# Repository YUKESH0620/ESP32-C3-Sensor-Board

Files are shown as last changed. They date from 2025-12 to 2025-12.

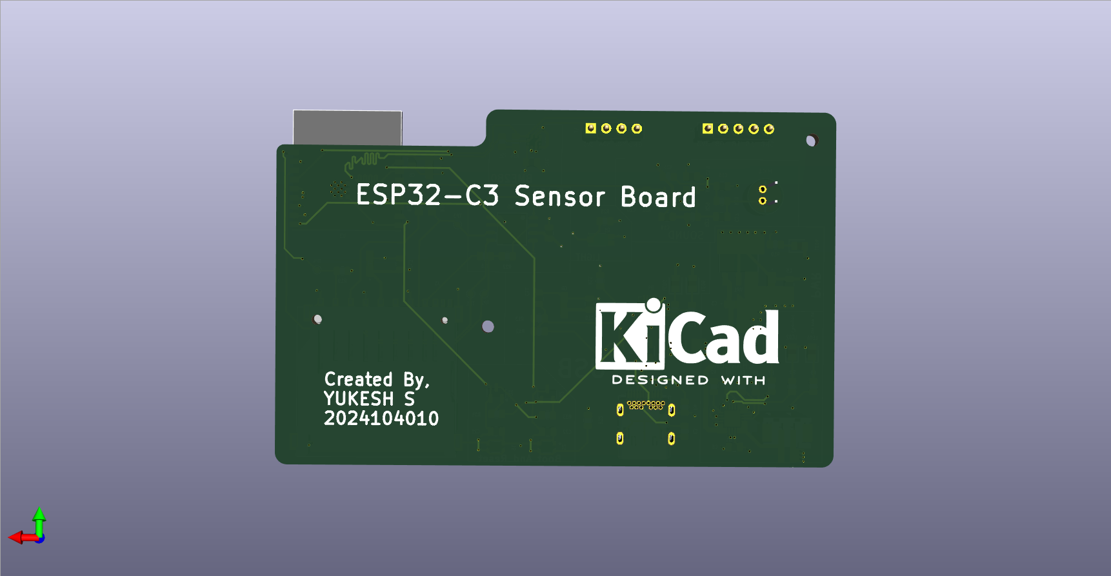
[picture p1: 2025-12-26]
images/3D_Renders/Screenshot 2025-12-26 091325.png

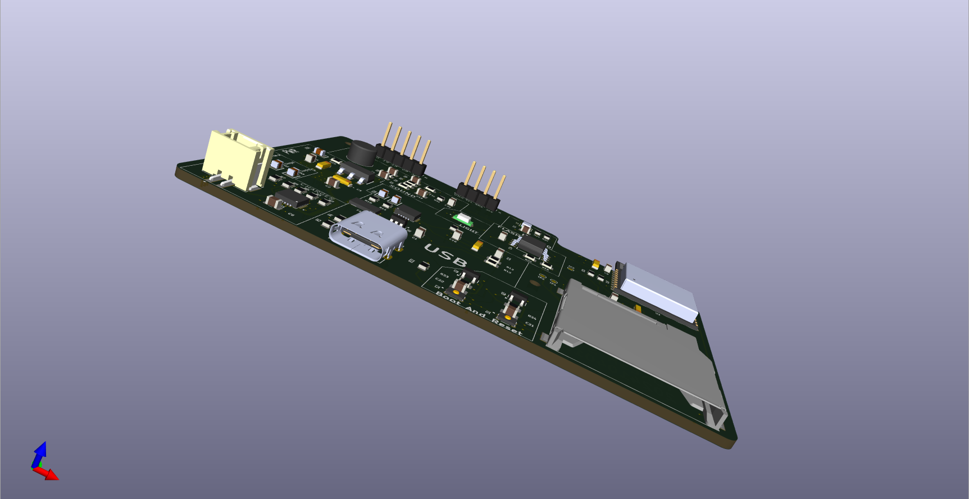
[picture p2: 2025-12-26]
images/3D_Renders/Screenshot 2025-12-26 091427.png

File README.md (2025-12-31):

# ESP32-C3 Smart Sensor Board

This repository contains the complete **hardware design** of a custom **ESP32-C3 based Smart Sensor Board**, including schematics, PCB layout, and documentation.

The design integrates **robust power management, multiple sensors, data storage, USB connectivity, and auto-programming**, making it suitable for **IoT, data logging, and embedded systems development**.

---

##  Board Images

###  Complete Schematic








###  PCB Layout


###  3D Views






---

##  System Architecture

### Functional Block Diagram
```text
USB-C / Li-Po Battery
│
MCP73831 Charger
│
+5V Rail
│
LM1117-3.3 LDO
│
+3.3V Rail
│
ESP32-C3 MCU
│ │ │ │
│ │ │ Microphone + MAX4466
│ │ BME280 (I2C)
│ LDR (ADC)
SD Card (SPI)
|
SPI Flash
```
---

##  Key Features

###  Power & Charging
- USB Type-C connector
- Li-Po charging using **MCP73831**
- JST battery connector
- LM1117-3.3 LDO regulator
- Power status LED

###  Microcontroller
- **ESP32-C3-WROOM-02**
- RISC-V core
- Wi-Fi + BLE
- USB-UART programmable

###  Sensors
- **BME280** – Temperature, humidity, pressure
- **Electret microphone + MAX4466 amplifier**
- **LDR photo sensor**

###  Storage
- SPI Flash memory (W25Q32)
- Micro SD card module (SPI)

###  Programming & Debug
- CP2102N USB-to-UART
- Auto-programming (DTR/RTS → EN/BOOT)
- Boot & Reset buttons
- Test points

---

##  Working Principle

### Power Section
- USB-C provides 5V
- MCP73831 safely charges Li-Po battery
- LM1117 converts 5V to regulated 3.3V
- Decoupling capacitors ensure stable rails

### MCU & Sensors
- ESP32-C3 communicates with:
  - BME280 via I²C
  - SD card & Flash via SPI
  - Microphone and LDR via ADC
- Data can be logged or transmitted wirelessly

### Programming
- USB-C → CP2102N
- DTR/RTS control BOOT & EN automatically
- Compatible with ESP-IDF and Arduino

---

## 🧾 Bill of Materials

###  Active Components

| Ref | Component | Value / Part |
|----|---|---|
| U1 | ESP32 MCU | ESP32-C3-WROOM-02 |
| U2 | Env Sensor | BME280 |
| U3 | USB-UART | CP2102N |
| U4 | Charger IC | MCP73831 |
| U5 | LDO Regulator | LM1117-3.3 |
| U6 | SPI Flash | W25Q32 |
| U7 | Mic Amplifier | MAX4466 |
| J1 | USB Connector | USB Type-C |
| J2 | Battery Connector | JST-PH-2 |
| J3 | SD Card Socket | SPI SD |

---

###  Resistors (From Schematic)

| Ref | Value | Purpose |
|----|---|---|
| R1 | 10kΩ | MCP73831 PROG |
| R2 | 10kΩ | MCP73831 PROG |
| R3 | 5.1kΩ | USB-C CC pull-down |
| R4 | 5.1kΩ | USB-C CC pull-down |
| R5 | 2kΩ | MCP73831 status |
| R6 | 20kΩ | MCP73831 status |
| R7 | 470Ω | Charging LED |
| R8 | 470Ω | Charged LED |
| R9 | 470Ω | Fault LED |
| R10 | 470Ω | Power LED |
| R11 | 1kΩ | USB VBUS link |
| R12 | 22.1kΩ | USB detection |
| R13 | 47.5kΩ | USB detection |
| R15 | 47k | Biasing resistor |
| R23 | 10kΩ | LDR voltage divider |
| R24 | 4.7kΩ | I²C pull-up |
| R25 | 4.7kΩ | I²C pull-up |
| R26 | 2kΩ | Mic bias |
| R27 | 1MΩ | Mic amp gain |
| R28 | 2kΩ | Mic bias |
| R29 | 1MΩ | Mic amp gain |
| R30 | 10kΩ | Mic amp |
| R31 | 2.2kΩ | Mic feedback |
| R32 | 10kΩ | Reset pull-up |
| R33 | 10kΩ | DTR control |
| R34 | 10kΩ | RTS control |

---

###  Capacitors (From Schematic)

| Ref | Value | Purpose |
|----|---|---|
| C1 | 0.1µF | USB decoupling |
| C2 | 0.1µF | LDO input |
| C3 | 10µF | LDO bulk |
| C4 | 10µF | LDO output |
| C5 | 0.1µF | LDO output |
| C6 | 1µF | MCP73831 |
| C7 | 10µF | ESP32 supply |
| C8 | 0.1µF | ESP32 decoupling |
| C10 | 0.1µF | Sensor decoupling |
| C14 | 0.1µF | Flash decoupling |
| C15 | 0.1µF | BME280 |
| C17 | 10nF | Mic coupling |
| C18 | 0.1µF | Mic supply |
| C19 | 1µF | Mic amp |
| C20 | 0.1µF | Mic feedback |
| C21 | 0.1µF | BOOT debounce |
| C22 | 1µF | RESET debounce |

---

##  Design Considerations

- Ground plane for EMI reduction
- ESP32 antenna keep-out respected
- Separate analog routing for microphone
- Decoupling capacitors close to ICs
- USB-C CC resistors correctly implemented
- Battery charging current set safely

---

##  Testing Strategy

- Power rail validation
- USB enumeration
- Battery charge & termination test
- Sensor I²C/SPI verification
- SD card read/write
- ADC noise testing (mic & LDR)

---
##  Revision History

### Rev-A (Initial Prototype)
- ESP32-C3 based sensor board
- Microphone connected to GPIO5 (ADC conflict with Wi-Fi)
- Fixed-gain microphone amplifier
- Photosensor output taken from incorrect pin
- No additional EMI filtering on power path

### Rev-B (Improved Design – Current)
- Resolved ADC conflict between Wi-Fi and microphone
- Improved analog signal quality
- Added EMI noise suppression
- Improved user interface and usability
---

##  Key Engineering Fixes & Improvements

ESP32 PCB prototype 2 improvements and fixes

### 1. ADC Conflict Resolution (Wi-Fi vs Microphone)
- Issue identified during testing: GPIO5 ADC unavailable when Wi-Fi is active
- Root cause: ADC resource conflict on ESP32-C3
- Solution:
  - Microphone OUT moved from GPIO5 → GPIO0 (ADC1)
  - CS_SD reassigned to GPIO5 as digital output
- Result: Microphone and Wi-Fi now operate simultaneously without conflict

### 2. Variable Gain Microphone Amplifier
- Replaced fixed gain network with trimmer potentiometer
- Gain range adjustable from **25× to 125×**
- Improves adaptability for different acoustic environments

### 3. Photosensor Signal Correction
- Output pin corrected from pin 3 → pin 1 as per datasheet
- Added RC filtering capacitors for noise reduction
- Result: Stable and accurate ADC readings

### 4. Analog Noise Reduction
- Added local decoupling capacitor near GPIO0 (MIC_OUT)
- Reduced high-frequency noise on ADC line

### 5. Improved User Interface
- Replaced small tact switches with larger buttons
- Better usability and reliability

### 6. Power Integrity Enhancement
- Added ferrite bead on charger output
- Purpose:
  - Suppress high-frequency switching noise from MCP73871
  - Reduce EMI affecting analog and RF sections

---
##  Design Status

- Rev-A: Initial schematic completed and reviewed
- Design improvements identified during schematic review
- Rev-B incorporates recommended fixes and optimizations
- Hardware fabrication and testing are pending

Note: Functional validation will be performed after PCB fabrication.

---
##  Validation Plan (Post-Fabrication)

- Verify Wi-Fi and microphone operation simultaneously
- Validate ADC stability for photosensor input
- Measure microphone gain range
- Check power rail noise and EMI behavior
- Confirm battery charging and boost operation

---

##  Applications

- Environmental monitoring
- IoT data logger
- Smart sensor node
- Academic & portfolio project
- Embedded systems experimentation

---

##  Future Enhancements

- Fuel gauge IC
- Enclosure design
- OTA firmware support
- EMI compliance testing
- Low-power optimization

---

## 👤 Author

**Yukesh S**  
Embedded Systems Enthusiast  

---

## 📜 License

This project is licensed under the MIT License.

You are free to use, modify, distribute, and commercialize this design,
provided that the original copyright notice and license text are included.

See the [LICENSE](LICENSE) file for full details.

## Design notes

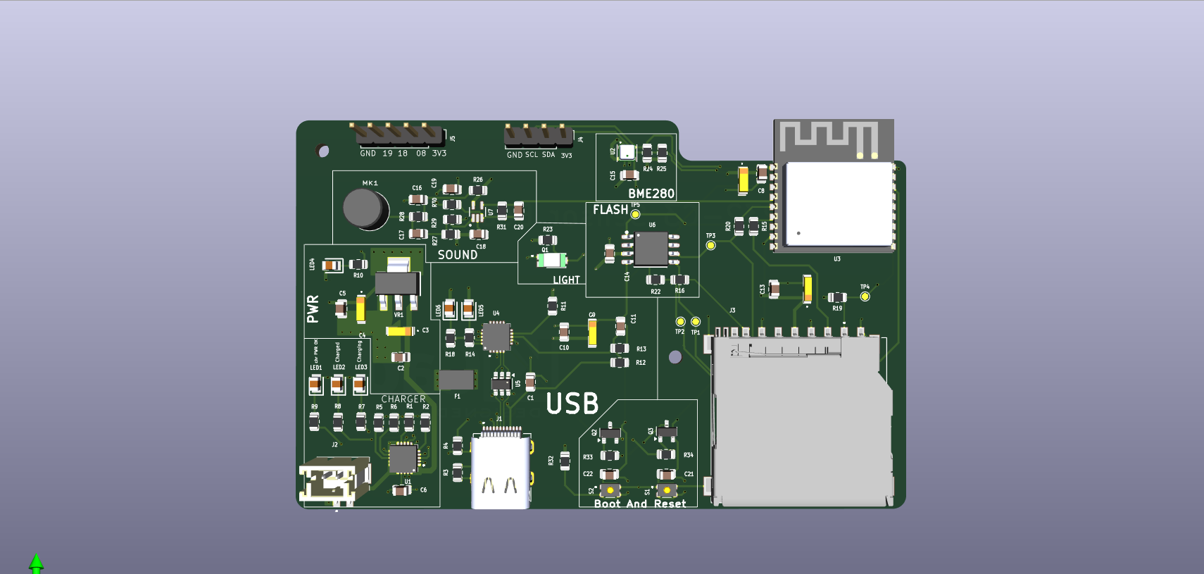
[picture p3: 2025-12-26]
images/3D_Renders/Screenshot 2025-12-26 091250.png

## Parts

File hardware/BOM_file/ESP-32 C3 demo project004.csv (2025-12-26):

ID | Designator | FootprintQuantity | Quantity | Designation | Supplier and ref
1 | C1 | C_0805_2012Metric | 1 | 0.1u
2 | C2 | C_0805_2012Metric | 1 | 0.1u
3 | C3 | C_0805_2012Metric | 1 | 10u
4 | C4 | C_0805_2012Metric | 1 | 10u
5 | C5 | C_0805_2012Metric | 1 | 0.1u
6 | C6 | C_0805_2012Metric | 1 | 1u
7 | C7 | C_0805_2012Metric | 1 | 10u
8 | C8 | C_0805_2012Metric | 1 | 0.1u
9 | C9 | C_0805_2012Metric | 1 | 4.7u
10 | C10 | C_0805_2012Metric | 1 | 0.1u
11 | C11 | C_0805_2012Metric | 1 | 1u
12 | C12 | C_0805_2012Metric | 1 | 10u
13 | C13 | C_0805_2012Metric | 1 | 0.1u
14 | C14 | C_0805_2012Metric | 1 | 0.1u
15 | C15 | C_0805_2012Metric | 1 | 0.1u
16 | C16 | C_0805_2012Metric | 1 | 0.1u
17 | C17 | C_0805_2012Metric | 1 | 10n
18 | C18 | C_0805_2012Metric | 1 | 0.1u
19 | C19 | C_0805_2012Metric | 1 | 1u
20 | C20 | C_0805_2012Metric | 1 | 0.1u
21 | C21 | C_0805_2012Metric | 1 | 0.1u
22 | C22 | C_0805_2012Metric | 1 | 1u
23 | F1 | FUSC3226X100N | 1 | 0ZCH0110AF2E
24 | J1 | BELFUSE_SS-52400-002 | 1 | SS-52400-002
25 | J2 | JST_B2B-PH-SM4-TB | 1 | B2B-PH-SM4-TB
26 | J3 | AMPHENOL_GSD090012SEU | 1 | B2B-PH-SM4-TB
27 | J4 | PinHeader_1x04_P2.54mm_Vertical | 1 | Conn_01x04_Pin
28 | J5 | PinHeader_1x05_P2.54mm_Vertical | 1 | Conn_01x05_Pin
29 | LED1 | LEDC2012X120N | 1 | LTST-C170TBKT
30 | LED2 | LEDC2012X120N | 1 | LTST-C170TBKT
31 | LED3 | LEDC2012X120N | 1 | LTST-C170TBKT
32 | LED4 | LEDC2012X120N | 1 | LTST-C170TBKT
33 | LED5 | LEDC2012X120N | 1 | LTST-C170TBKT
34 | LED6 | LEDC2012X120N | 1 | LTST-C170TBKT
35 | MK1 | CUI_CMC-5042PF-AC | 1 | CMC-5042PF-AC
36 | Q1 | TRANS_TEMT6000X01 | 1 | TEMT6000X01
37 | Q2 | SOT-23 | 1 | BC817
38 | Q3 | SOT-23 | 1 | BC817
39 | R1 | R_0805_2012Metric | 1 | 10k
40 | R2 | R_0805_2012Metric | 1 | 10k
41 | R3 | R_0805_2012Metric | 1 | 5k1
42 | R4 | R_0805_2012Metric | 1 | 5k1
43 | R5 | R_0805_2012Metric | 1 | 2k
44 | R6 | R_0805_2012Metric | 1 | 20k
45 | R7 | R_0805_2012Metric | 1 | 470
46 | R8 | R_0805_2012Metric | 1 | 470
47 | R9 | R_0805_2012Metric | 1 | 470
48 | R10 | R_0805_2012Metric | 1 | 470
49 | R11 | R_0805_2012Metric | 1 | 1k
50 | R12 | R_0805_2012Metric | 1 | 22k1
51 | R13 | R_0805_2012Metric | 1 | 47k5
52 | R14 | R_0805_2012Metric | 1 | 470
53 | R15 | R_0805_2012Metric | 1 | 50
54 | R16 | R_0805_2012Metric | 1 | 50
55 | R18 | R_0805_2012Metric | 1 | 470
56 | R19 | R_0805_2012Metric | 1 | 10k
57 | R20 | R_0805_2012Metric | 1 | 50
58 | R22 | R_0805_2012Metric | 1 | 50
59 | R23 | R_0805_2012Metric | 1 | 10k
60 | R24 | R_0805_2012Metric | 1 | 4k7
61 | R25 | R_0805_2012Metric | 1 | 4k7
62 | R26 | R_0805_2012Metric | 1 | 2k
63 | R27 | R_0805_2012Metric | 1 | 1M
64 | R28 | R_0805_2012Metric | 1 | 2k
65 | R29 | R_0805_2012Metric | 1 | 1M
66 | R30 | R_0805_2012Metric | 1 | 10k
67 | R31 | R_0805_2012Metric | 1 | 100k
68 | R32 | R_0805_2012Metric | 1 | 10k
69 | R33 | R_0805_2012Metric | 1 | 10k
70 | R34 | R_0805_2012Metric | 1 | 10k
71 | S1 | SW_USLPT2819DT2TR | 1 | Boot
72 | S2 | SW_USLPT2819DT2TR | 1 | Reset
73 | TP1 | TestPoint_Pad_D1.0mm | 1 | Test MOSI
74 | TP2 | TestPoint_Pad_D1.0mm | 1 | Test MISO
75 | TP3 | TestPoint_Pad_D1.0mm | 1 | Test SCLK
76 | TP4 | TestPoint_Pad_D1.0mm | 1 | Test CS-SD
77 | TP5 | TestPoint_Pad_D1.0mm | 1 | Test CS
78 | U1 | QFN50P400X400X100-21N | 1 | MCP73871
79 | U2 | PSON65P250X250X100-8N | 1 | BME280
80 | U3 | MODULE_ESP32-C3-WROOM-02-H4 | 1 | ESP32-C3-WROOM-02-H4
81 | U4 | QFN50P400X400X100-21N | 1 | MCP73871
82 | U5 | SOT-23-6 | 1 | USBLC6-2SC6
83 | U6 | SOIC127P790X216-8N | 1 | W25Q32JVSSIQ
84 | U7 | SOT65P210X110-5N | 1 | MAX4466EXK
85 | VR1 | VREG_LM1117MPX-3.3 | 1 | LM1117MPX-3.3

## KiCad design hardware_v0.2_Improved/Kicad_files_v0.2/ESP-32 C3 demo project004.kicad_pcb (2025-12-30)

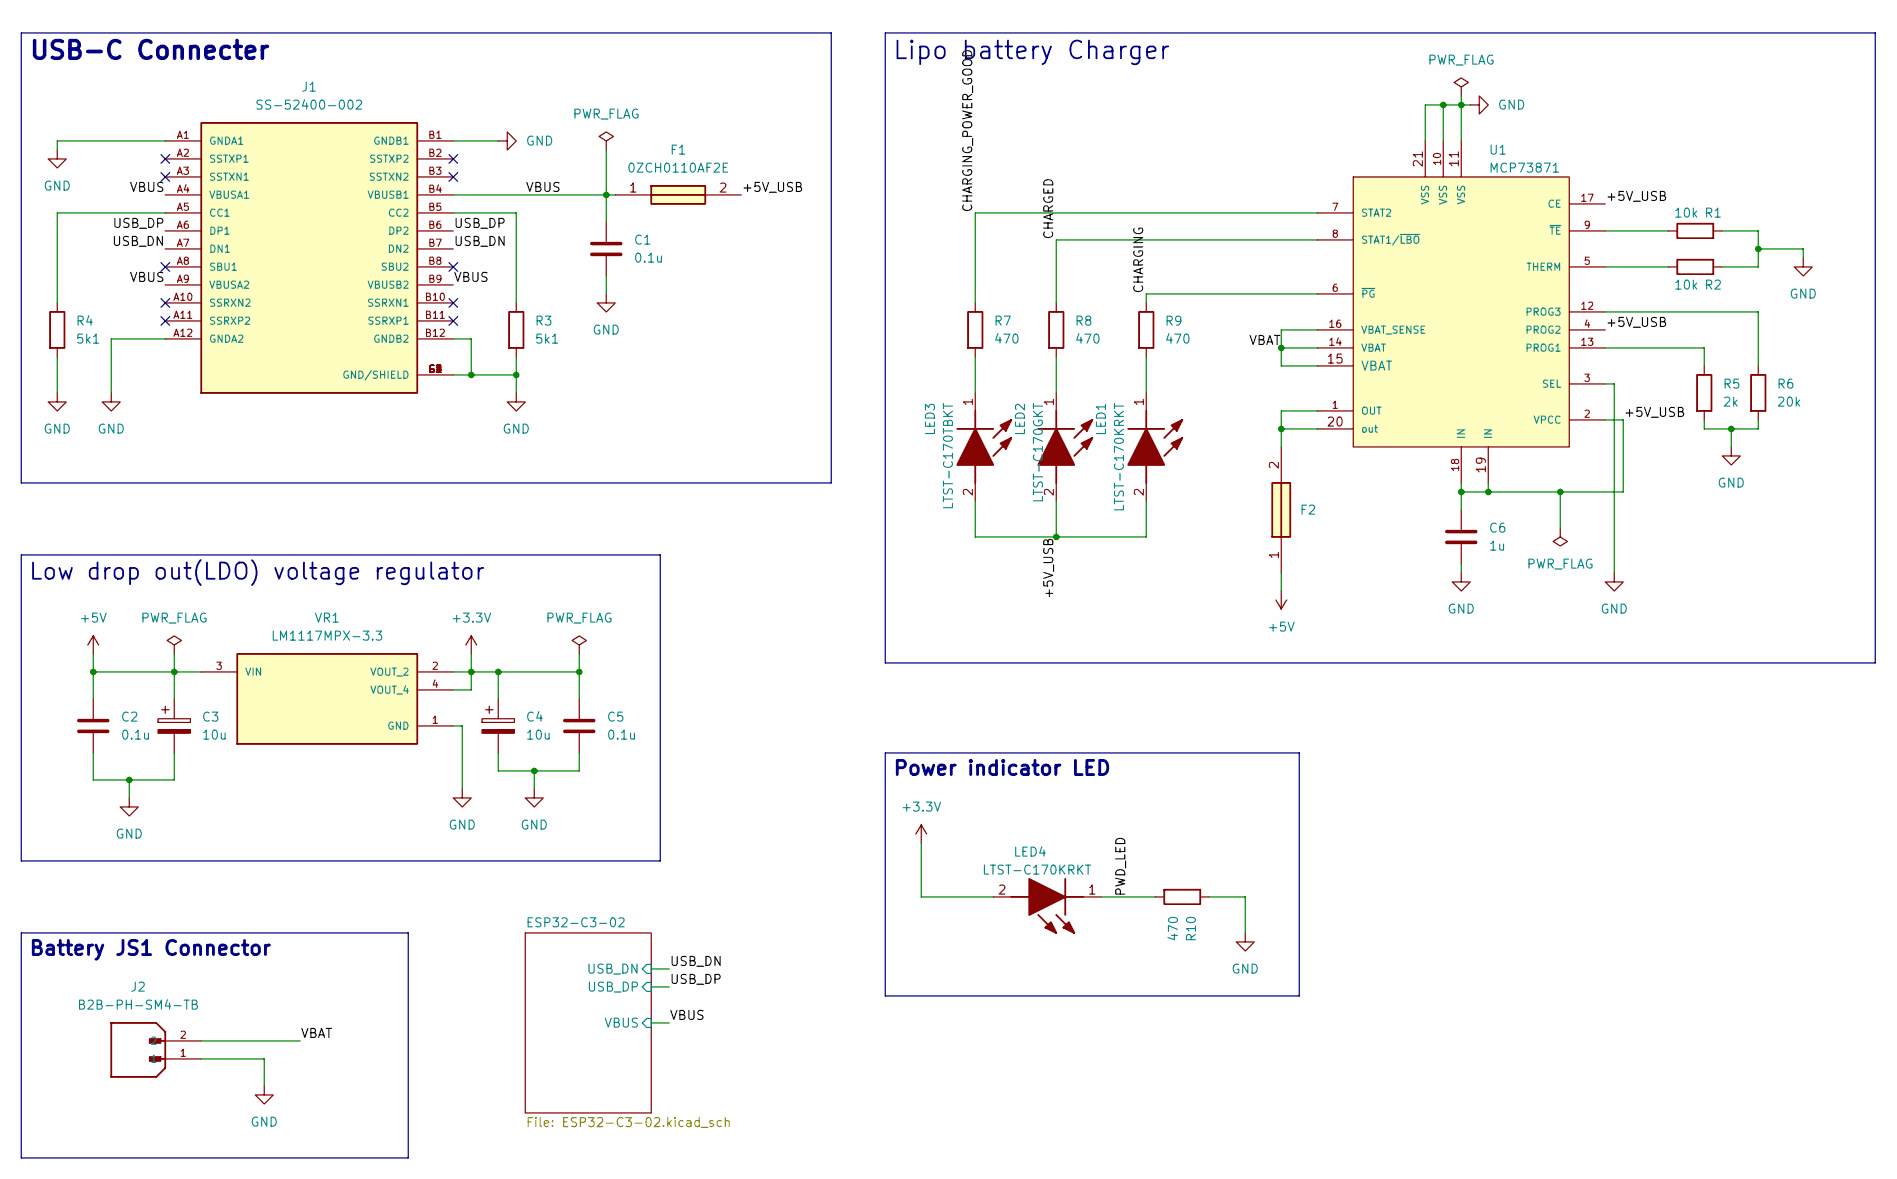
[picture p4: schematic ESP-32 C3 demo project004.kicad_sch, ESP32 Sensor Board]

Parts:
C1, C2, C5: 0.1u; C_0805_2012Metric
C3, C4: 10u; T491A
C6: 1u; C_0805_2012Metric
F1, F2: 0ZCH0110AF2E; FUSC3226X100N; Manufacturer_Part_Number 0ZCH0110AF2E
J1: SS-52400-002; BELFUSE_SS-52400-002; PARTREV A0
J2: B2B-PH-SM4-TB; JST_B2B-PH-SM4-TB; PARTREV N/A
LED1, LED4: LTST-C170KRKT; LEDC2012X120N; Manufacturer_Part_Number LTST-C170KRKT; Mouser Part Number 859-LTST-C170KRKT
LED2: LTST-C170GKT; LEDC2012X120N; Manufacturer_Part_Number LTST-C170GKT; Mouser Part Number 859-LTST-C170GKT
LED3: LTST-C170TBKT; LEDC2012X120N; Manufacturer_Part_Number LTST-C170TBKT; Mouser Part Number 859-LTST-C170TBKT
R1, R2: 10k; R_0805_2012Metric
R3, R4: 5k1; R_0805_2012Metric
R5: 2k; R_0805_2012Metric
R6: 20k; R_0805_2012Metric
R7, R8, R9, R10: 470; R_0805_2012Metric
U1: MCP73871; QFN50P400X400X100-21N; PARTREV D
VR1: LM1117MPX-3.3; VREG_LM1117MPX-3.3

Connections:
+3.3V: C4.1, C5.1, LED4.2 (A), VR1.2 (VOUT_2), VR1.4 (VOUT_4); also elsewhere on the board
+5V: C2.1, C3.1, F2.1, VR1.3 (VIN)
/+5V_USB: C6.1, F1.2, LED1.2 (A), LED2.2 (A), LED3.2 (A), U1.2 (VPCC), U1.4 (PROG2), U1.17 (CE), U1.18 (IN), U1.19 (IN)
/CHARGED: R8.1, U1.8 (STAT1/~LBO)
/CHARGING: R9.1, U1.6 (~PG)
/CHARGING_POWER_GOOD: R7.1, U1.7 (STAT2)
/PWD_LED: LED4.1 (K), R10.2
/USB_DN: J1.A7 (DN1), J1.B7 (DN2); also elsewhere on the board
/USB_DP: J1.A6 (DP1), J1.B6 (DP2); also elsewhere on the board
/VBAT: J2.2, U1.14 (VBAT), U1.15 (VBAT), U1.16 (VBAT_SENSE)
/VBUS: C1.1, F1.1, J1.A4 (VBUSA1), J1.A9 (VBUSA2), J1.B4 (VBUSB1), J1.B9 (VBUSB2); also elsewhere on the board
GND: C1.2, C2.2, C3.2, C4.2, C5.2, C6.2, J1.A1 (GNDA1), J1.A12 (GNDA2), J1.B1 (GNDB1), J1.B12 (GNDB2), J1.G1 (GND/SHIELD), J1.G2 (GND/SHIELD), J1.G3 (GND/SHIELD), J1.G4 (GND/SHIELD), J1.S1 (GND/SHIELD), J1.S2 (GND/SHIELD), J1.S3 (GND/SHIELD), J1.S4 (GND/SHIELD), J2.1, R1.2, R2.2, R3.2, R4.2, R5.2, R6.2, R10.1, U1.3 (SEL), U1.10 (VSS), U1.11 (VSS), U1.21 (VSS), VR1.1 (GND); also elsewhere on the board
unnamed: J1.A5 (CC1), R4.1
unnamed: J1.B5 (CC2), R3.1
unnamed: LED1.1 (K), R9.2
unnamed: LED2.1 (K), R8.2
unnamed: LED3.1 (K), R7.2
unnamed: F2.2, U1.1 (OUT), U1.20 (out)
unnamed: R5.1, U1.13 (PROG1)
unnamed: R6.1, U1.12 (PROG3)
unnamed: R2.1, U1.5 (THERM)
unnamed: R1.1, U1.9 (~TE)

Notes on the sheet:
Lipo battery Charger
USB-C Connecter
Power indicator LED
Battery JS1 Connector
Low drop out(LDO) voltage regulator

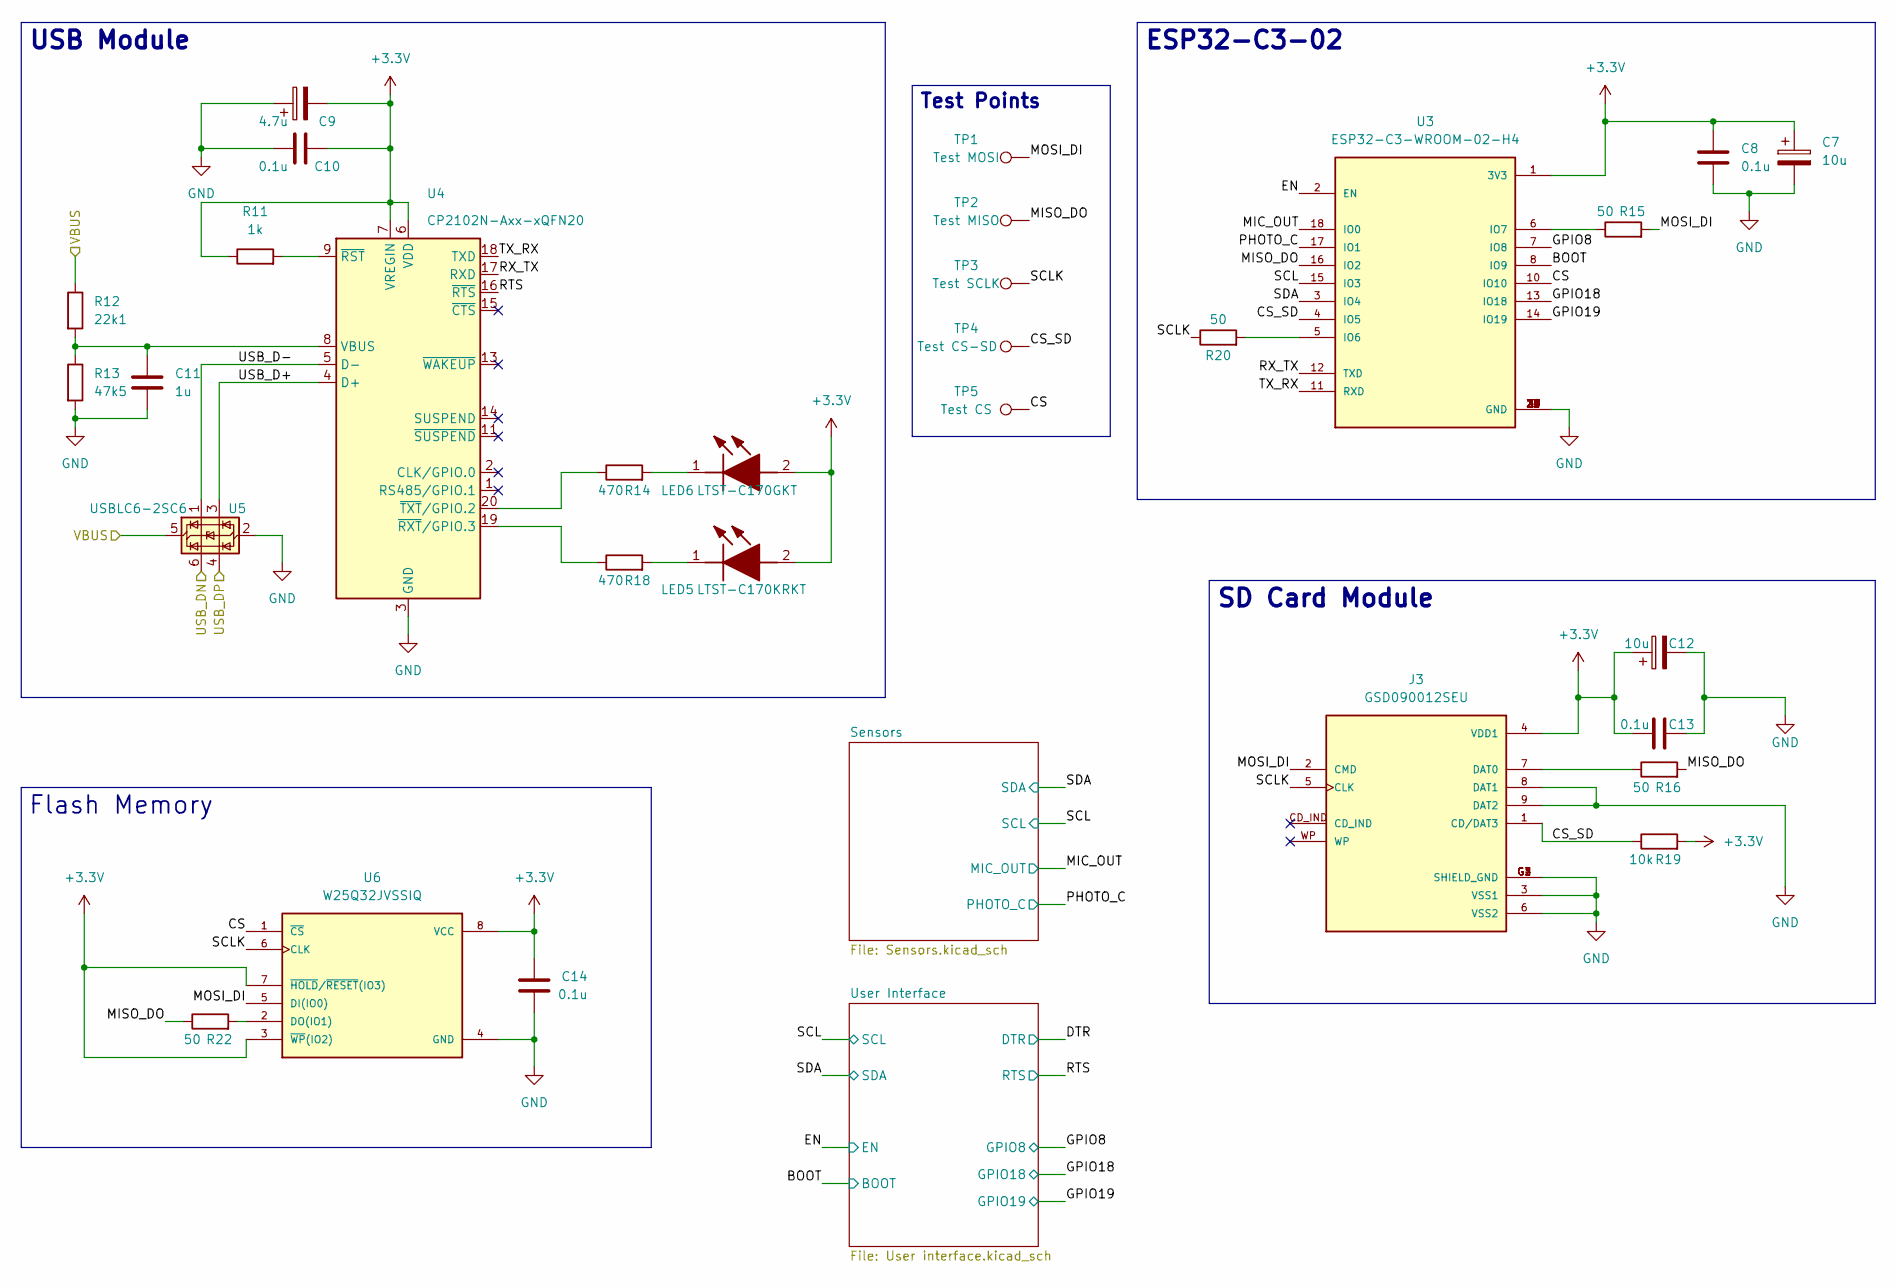
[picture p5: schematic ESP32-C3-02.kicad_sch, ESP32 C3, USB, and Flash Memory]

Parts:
C7, C12: 10u; T491A
C8, C10, C13, C14: 0.1u; C_0805_2012Metric
C9: 4.7u; T491A
C11: 1u; C_0805_2012Metric
J3: GSD090012SEU; AMPHENOL_GSD090012SEU; PARTREV E
LED5: LTST-C170GKT; LEDC2012X120N; Manufacturer_Part_Number LTST-C170GKT; Mouser Part Number 859-LTST-C170GKT
LED6: LTST-C170KRKT; LEDC2012X120N; Manufacturer_Part_Number LTST-C170KRKT; Mouser Part Number 859-LTST-C170KRKT
R11: 1k; R_0805_2012Metric
R12: 22k1; R_0805_2012Metric
R13: 47k5; R_0805_2012Metric
R14, R18: 470; R_0805_2012Metric
R15, R16, R20, R22: 50; R_0805_2012Metric
R19: 10k; R_0805_2012Metric
TP1: Test MOSI; TestPoint_Pad_D1.0mm
TP2: Test MISO; TestPoint_Pad_D1.0mm
TP3: Test SCLK; TestPoint_Pad_D1.0mm
TP4: Test CS-SD; TestPoint_Pad_D1.0mm
TP5: Test CS; TestPoint_Pad_D1.0mm
U3: ESP32-C3-WROOM-02-H4; MODULE_ESP32-C3-WROOM-02-H4
U4: CP2102N-Axx-xQFN20; QFN50P400X400X100-21N
U5: USBLC6-2SC6; SOT-23-6
U6: W25Q32JVSSIQ; SOIC127P790X216-8N; M_PART_NUMBER W25QXX

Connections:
+3.3V: C7.1, C8.1, C9.2, C10.2, C12.1, C13.1, C14.2, J3.4 (VDD1), LED5.2 (A), LED6.2 (A), R11.1, R19.2, U3.1 (3V3), U4.6 (VDD), U4.7 (VREGIN), U6.3 (~WP(IO2)), U6.7 (~HOLD/~RESET(IO3)), U6.8 (VCC); also elsewhere on the board
/ESP32-C3-02/BOOT: U3.8 (IO9); also elsewhere on the board
/ESP32-C3-02/CS: TP5.1, U3.10 (IO10), U6.1 (~CS)
/ESP32-C3-02/CS_SD: J3.1 (CD/DAT3), R19.1, TP4.1, U3.4 (IO5)
/ESP32-C3-02/EN: U3.2 (EN); also elsewhere on the board
/ESP32-C3-02/GPIO8: U3.7 (IO8); also elsewhere on the board
/ESP32-C3-02/GPIO18: U3.13 (IO18); also elsewhere on the board
/ESP32-C3-02/GPIO19: U3.14 (IO19); also elsewhere on the board
/ESP32-C3-02/MIC_OUT: U3.18 (IO0); also elsewhere on the board
/ESP32-C3-02/MISO_DO: R16.2, R22.1, TP2.1, U3.16 (IO2)
/ESP32-C3-02/MOSI_DI: J3.2 (CMD), R15.2, TP1.1, U6.5 (DI(IO0))
/ESP32-C3-02/PHOTO_C: U3.17 (IO1); also elsewhere on the board
/ESP32-C3-02/RTS: U4.16 (~RTS); also elsewhere on the board
/ESP32-C3-02/RX_TX: U3.12 (TXD), U4.17 (RXD)
/ESP32-C3-02/SCL: U3.15 (IO3); also elsewhere on the board
/ESP32-C3-02/SCLK: J3.5 (CLK), R20.1, TP3.1, U6.6 (CLK)
/ESP32-C3-02/SDA: U3.3 (IO4); also elsewhere on the board
/ESP32-C3-02/TX_RX: U3.11 (RXD), U4.18 (TXD)
/ESP32-C3-02/USB_D+: U4.4 (D+), U5.3 (I/O2)
/ESP32-C3-02/USB_D-: U4.5 (D-), U5.1 (I/O1)
/USB_DN: U5.6 (I/O1); also elsewhere on the board
/USB_DP: U5.4 (I/O2); also elsewhere on the board
/VBUS: R12.1, U5.5 (VBUS); also elsewhere on the board
GND: C7.2, C8.2, C9.1, C10.1, C11.2, C12.2, C13.2, C14.1, J3.3 (VSS1), J3.6 (VSS2), J3.8 (DAT1), J3.9 (DAT2), J3.G1 (SHIELD_GND), J3.G2 (SHIELD_GND), J3.G3 (SHIELD_GND), J3.G4 (SHIELD_GND), R13.2, U3.9 (GND), U3.19 (GND), U3.20 (GND), U3.21 (GND), U3.22 (GND), U3.23 (GND), U3.24 (GND), U3.25 (GND), U3.26 (GND), U3.27 (GND), U3.28 (GND), U3.29 (GND), U3.30 (GND), U3.31 (GND), U3.32 (GND), U3.33 (GND), U3.34 (GND), U3.35 (GND), U3.36 (GND), U3.37 (GND), U3.38 (GND), U3.39 (GND), U4.3 (GND), U4.12 (GND), U4.21 (GND), U5.2 (GND), U6.4 (GND); also elsewhere on the board
unnamed: J3.7 (DAT0), R16.1
unnamed: LED5.1 (K), R14.2
unnamed: LED6.1 (K), R18.2
unnamed: R20.2, U3.5 (IO6)
unnamed: R15.1, U3.6 (IO7)
unnamed: C11.1, R12.2, R13.1, U4.8 (VBUS)
unnamed: R11.2, U4.9 (~RST)
unnamed: R18.1, U4.19 (~RXT/GPIO.3)
unnamed: R14.1, U4.20 (~TXT/GPIO.2)
unnamed: R22.2, U6.2 (DO(IO1))

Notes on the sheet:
SD Card Module
Flash Memory
ESP32-C3-02
Test Points
USB Module

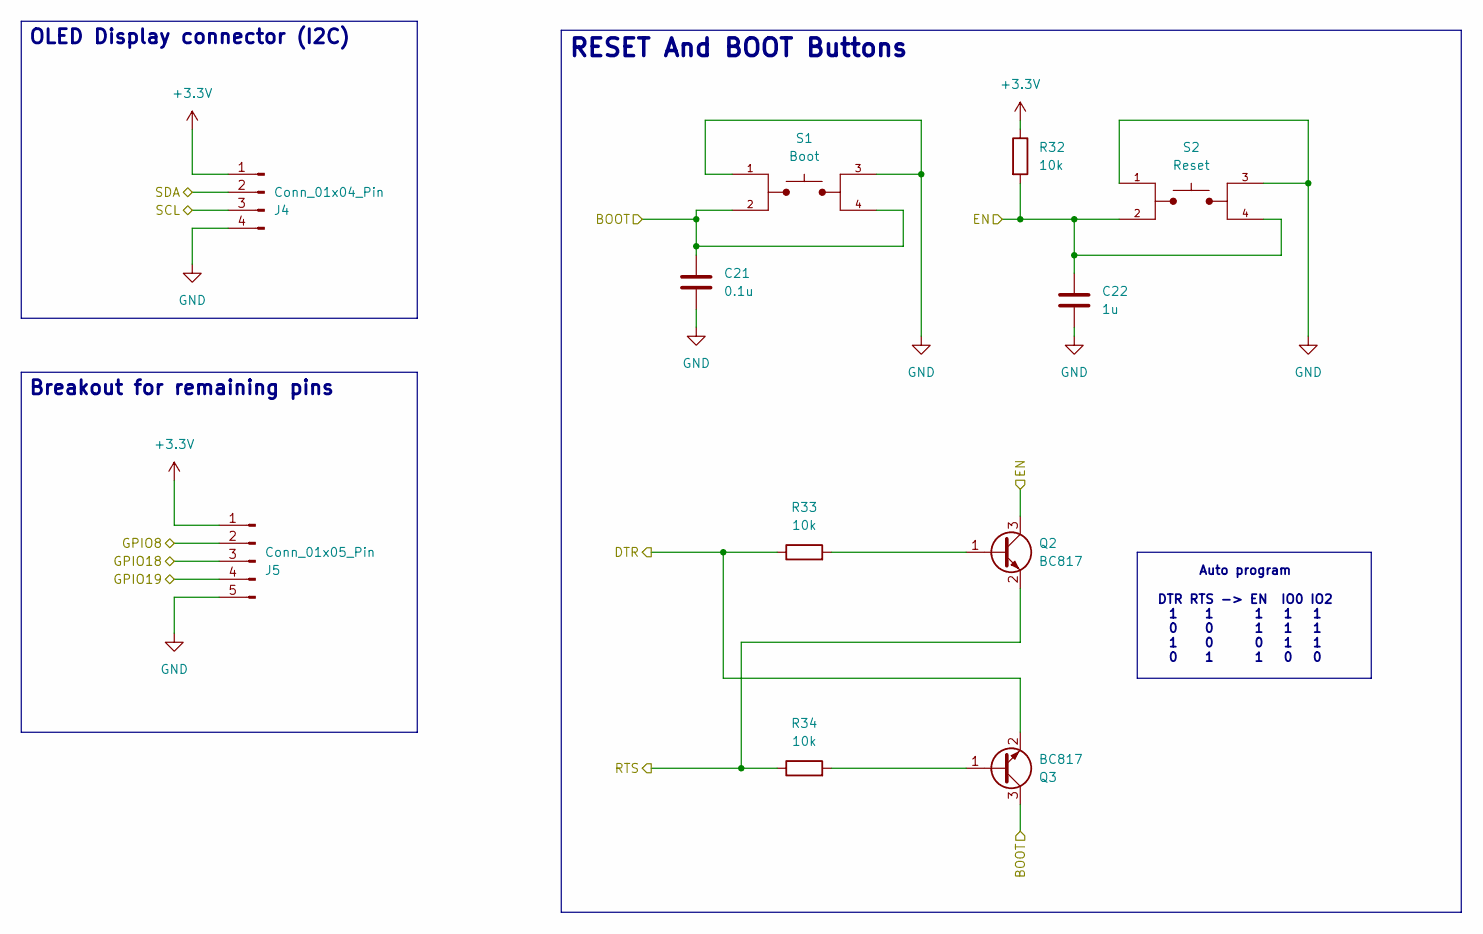
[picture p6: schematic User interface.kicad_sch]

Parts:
C21: 0.1u; C_0805_2012Metric
C22: 1u; C_0805_2012Metric
J4: Conn_01x04_Pin; PinHeader_1x04_P2.54mm_Vertical
J5: Conn_01x05_Pin; PinHeader_1x05_P2.54mm_Vertical
Q2, Q3: BC817; SOT-23
R32, R33, R34: 10k; R_0805_2012Metric
S1: Boot; SW_TL3305AF260QG; PARTREV C
S2: Reset; SW_TL3305AF260QG; PARTREV C

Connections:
+3.3V: J4.1, J5.1, R32.1; also elsewhere on the board
/ESP32-C3-02/BOOT: C21.1, Q3.3 (C), S1.2, S1.4; also elsewhere on the board
/ESP32-C3-02/DTR: Q3.2 (E), R33.1
/ESP32-C3-02/EN: C22.1, Q2.3 (C), R32.2, S2.2, S2.4; also elsewhere on the board
/ESP32-C3-02/GPIO8: J5.2; also elsewhere on the board
/ESP32-C3-02/GPIO18: J5.3; also elsewhere on the board
/ESP32-C3-02/GPIO19: J5.4; also elsewhere on the board
/ESP32-C3-02/RTS: Q2.2 (E), R34.1; also elsewhere on the board
/ESP32-C3-02/SCL: J4.3; also elsewhere on the board
/ESP32-C3-02/SDA: J4.2; also elsewhere on the board
GND: C21.2, C22.2, J4.4, J5.5, S1.1, S1.3, S2.1, S2.3; also elsewhere on the board
unnamed: Q2.1 (B), R33.2
unnamed: Q3.1 (B), R34.2

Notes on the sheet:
Auto program DTR RTS -> EN IO0 IO2 1 1 1 1 1 0 0 1 1 1 1 0 0 1 1 0 1 1 0 0
Breakout for remaining pins
RESET And BOOT Buttons
OLED Display connector (I2C)

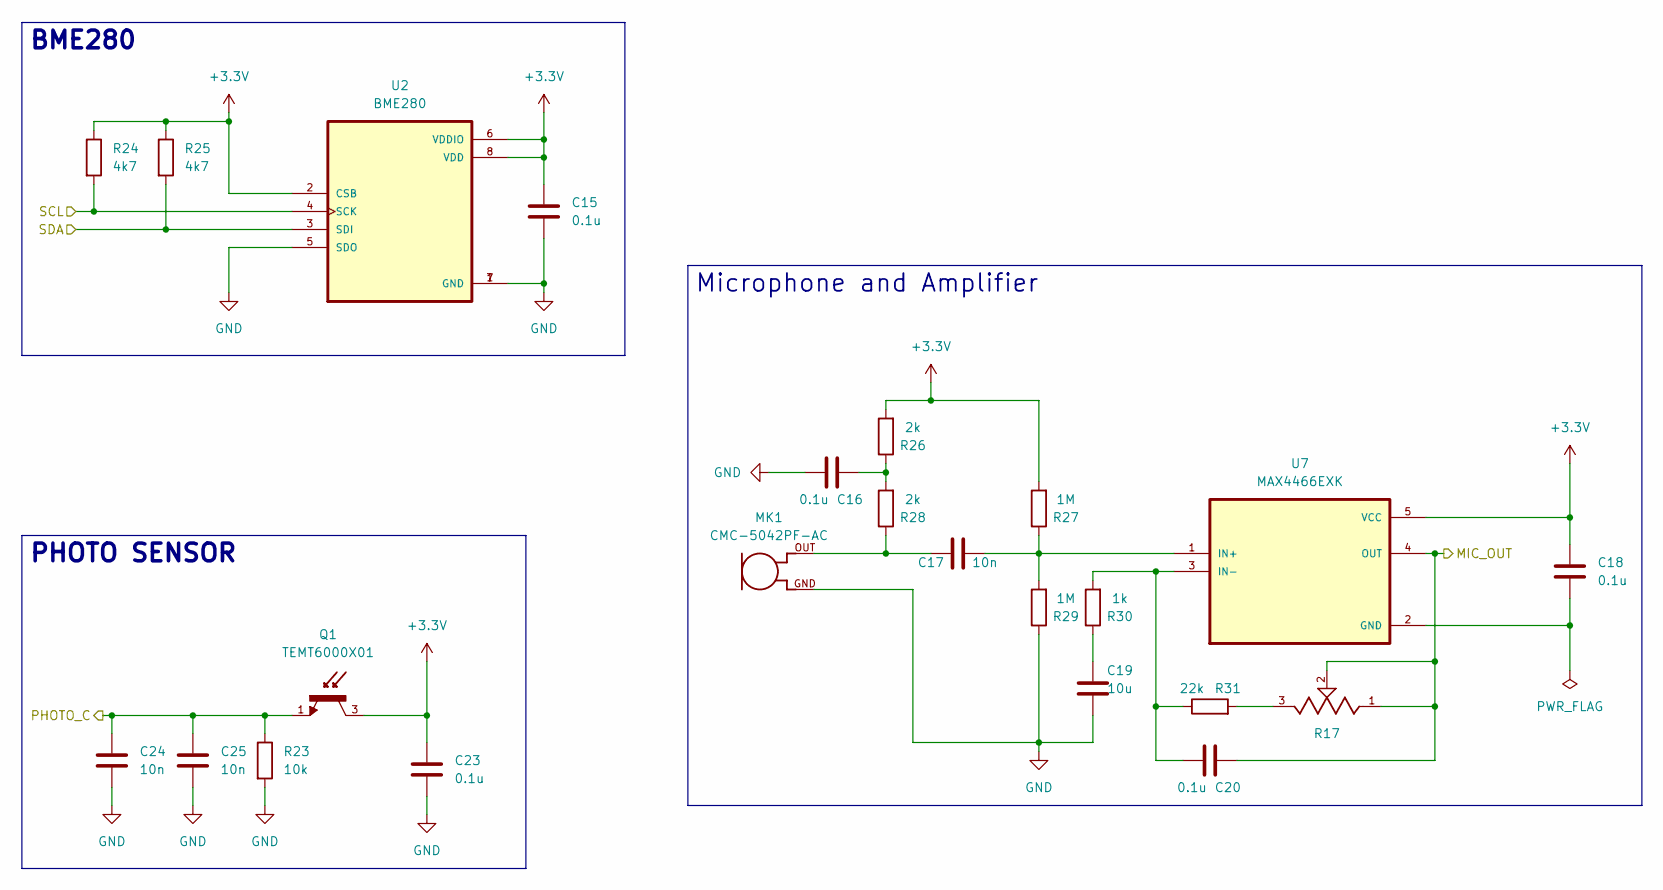
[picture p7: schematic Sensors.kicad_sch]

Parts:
C15, C16, C18, C20, C23: 0.1u; C_0805_2012Metric
C17, C24, C25: 10n; C_0805_2012Metric
C19: 10u; C_0805_2012Metric
MK1: CMC-5042PF-AC; CUI_CMC-5042PF-AC
Q1: TEMT6000X01; TRANS_TEMT6000X01; PARTREV 1.9
R17: 35WR100KLFTR; TRIM_35WR100KLFTR; PARTREV D
R23: 10k; R_0805_2012Metric
R24, R25: 4k7; R_0805_2012Metric
R26, R28: 2k; R_0805_2012Metric
R27, R29: 1M; R_0805_2012Metric
R30: 1k; R_0805_2012Metric
R31: 22k; R_0805_2012Metric
U2: BME280; PSON65P250X250X100-8N
U7: MAX4466EXK; SOT65P210X110-5N

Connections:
+3.3V: C15.1, C18.1, C23.1, Q1.3, R24.1, R25.1, R26.2, R27.2, U2.2 (CSB), U2.6 (VDDIO), U2.8 (VDD), U7.5 (VCC); also elsewhere on the board
/ESP32-C3-02/MIC_OUT: C20.2, R17.1, R17.2, U7.4 (OUT); also elsewhere on the board
/ESP32-C3-02/PHOTO_C: C24.1, C25.1, Q1.1, R23.1; also elsewhere on the board
/ESP32-C3-02/SCL: R24.2, U2.4 (SCK); also elsewhere on the board
/ESP32-C3-02/SDA: R25.2, U2.3 (SDI); also elsewhere on the board
GND: C15.2, C16.1, C19.1, C23.2, C24.2, C25.2, MK1.GND, R23.2, R29.1, U2.1 (GND), U2.5 (SDO), U2.7 (GND); also elsewhere on the board
unnamed: C16.2, R26.1, R28.2
unnamed: C17.2, MK1.OUT, R28.1
unnamed: C19.2, R30.1
unnamed: R17.3, R31.2
unnamed: C18.2, U7.2 (GND)
unnamed: C17.1, R27.1, R29.2, U7.1 (IN+)
unnamed: C20.1, R30.2, R31.1, U7.3 (IN-)

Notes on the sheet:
BME280
Microphone and Amplifier
PHOTO SENSOR

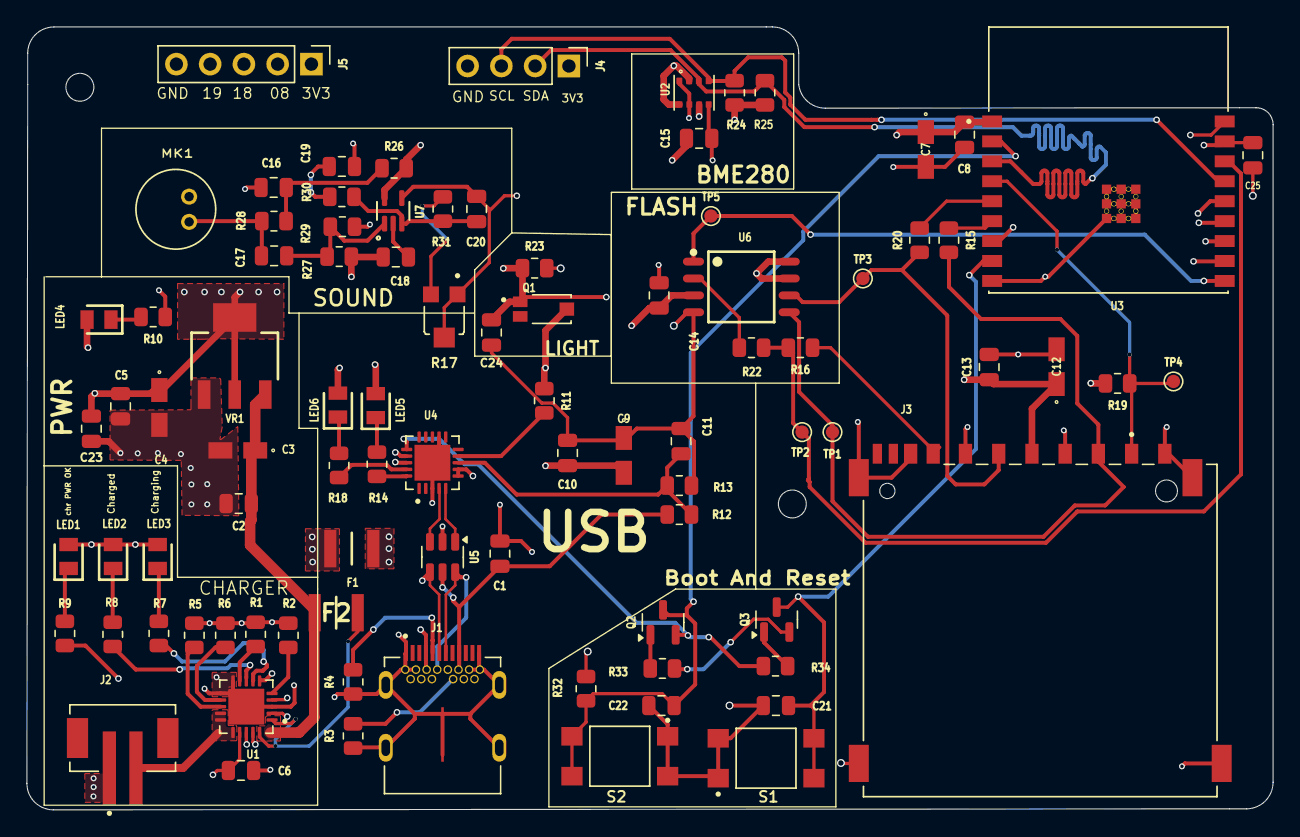
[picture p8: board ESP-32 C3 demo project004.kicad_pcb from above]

Board: 4 copper layers, 93.8 x 58.9 mm, 90 parts (0 on the bottom side), 61 nets.
